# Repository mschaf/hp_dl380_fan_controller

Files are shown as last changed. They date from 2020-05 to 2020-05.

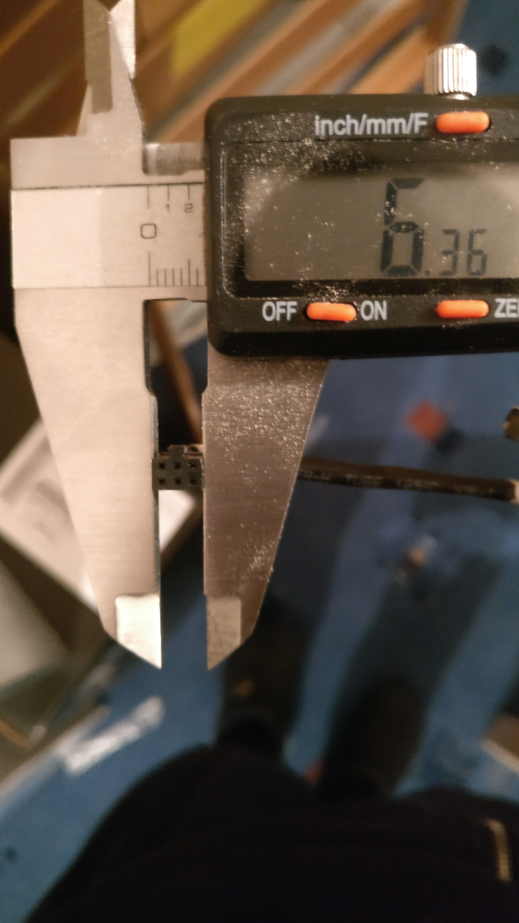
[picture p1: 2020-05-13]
reference images/IMG_20200121_184714.jpg

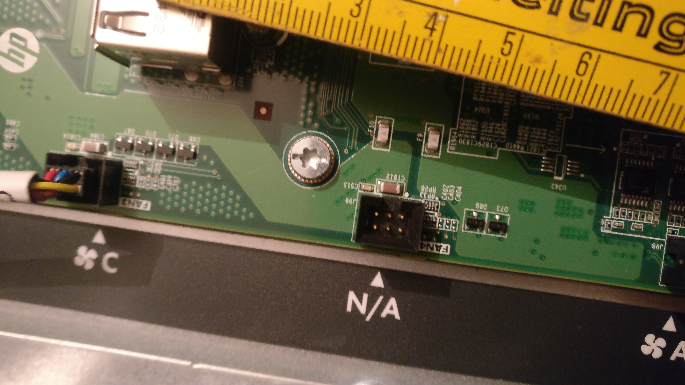
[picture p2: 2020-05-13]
reference images/IMG_20200121_184526.jpg

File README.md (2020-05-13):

## HP DL380 Fan Controller

A fan controller for my DL380e gen8, should work with similar servers as well. It takes the fan signal from the mainboard and divides it by 2, expect it is over 70% then it just passed it as it is. 

It gets its power and commands from the internal USB port of the server. It acts like a serial device and can be configured via the serial console. 

Firmware for the PIC microcontroller is written with MPLAB X in c.
The PCB layout is made in KiCAD and can be ordered from services like JLCPCB with the files from the gerbers directory.

Its not perfect, there are still some features it should have, like saving the config to survive a power cylce.

The cables needed can either be hacked together with some spare fan cables from HP or made yourself. The connectors are somewhat custom, or at least I could not find them online. You can use 2mm pitch standart pin sockets and grind them down a litte ti fit in the header on the mainbaord.

Fan Controller Installed

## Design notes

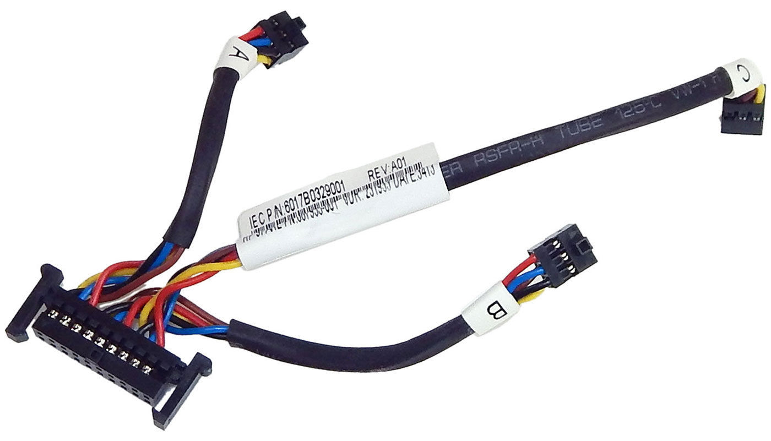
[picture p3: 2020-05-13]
reference images/s-l1600.jpg

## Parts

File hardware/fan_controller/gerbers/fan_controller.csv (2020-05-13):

Comment | Designator | Footprint
10k? | R12,R1,R2,R3,R4,R5,R6,R7,R11,R13,R14,R15,R16 | R_0805_2012Metric
10uF | C1,C17 | C_1206_3216Metric
100nF | C2,C3,C4,C5,C6,C7,C8,C9,C10,C11,C12,C13 | C_0805_2012Metric
15pF | C14,C15 | C_0805_2012Metric
10uF | C16 | CP_Elec_4x5.4
1uF | C18 | C_0805_2012Metric
LED_Dual_AACC | D1,D2,D3 | EVL 15-22 R6G6C
Conn_02x05_Odd_Even | J1,J2 | IDC-Header_2x05_P2.54mm_Vertical
ICSP | J3 | PinSocket_1x05_P2.54mm_Vertical
Jumper_NC_Dual | JP1 | PinSocket_1x03_P2.54mm_Vertical
100? | R8,R9,R10,R17,R18,R19,R20 | R_0805_2012Metric
100K? | R21 | R_0805_2012Metric
390? | R22 | R_0805_2012Metric
470? | R23,R24,R25,R26,R27,R28 | R_0805_2012Metric
240? | R29 | R_0805_2012Metric
PIC24FJ128GB204 | U1 | TQFP-44_10x10mm_P0.8mm
LD1117-R | U2 | SOT-223-3_TabPin2
8 MHz | Y1 | smd_quarz

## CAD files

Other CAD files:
hardware/fan_controller/gerbers/fan_controller-PTH.dxf

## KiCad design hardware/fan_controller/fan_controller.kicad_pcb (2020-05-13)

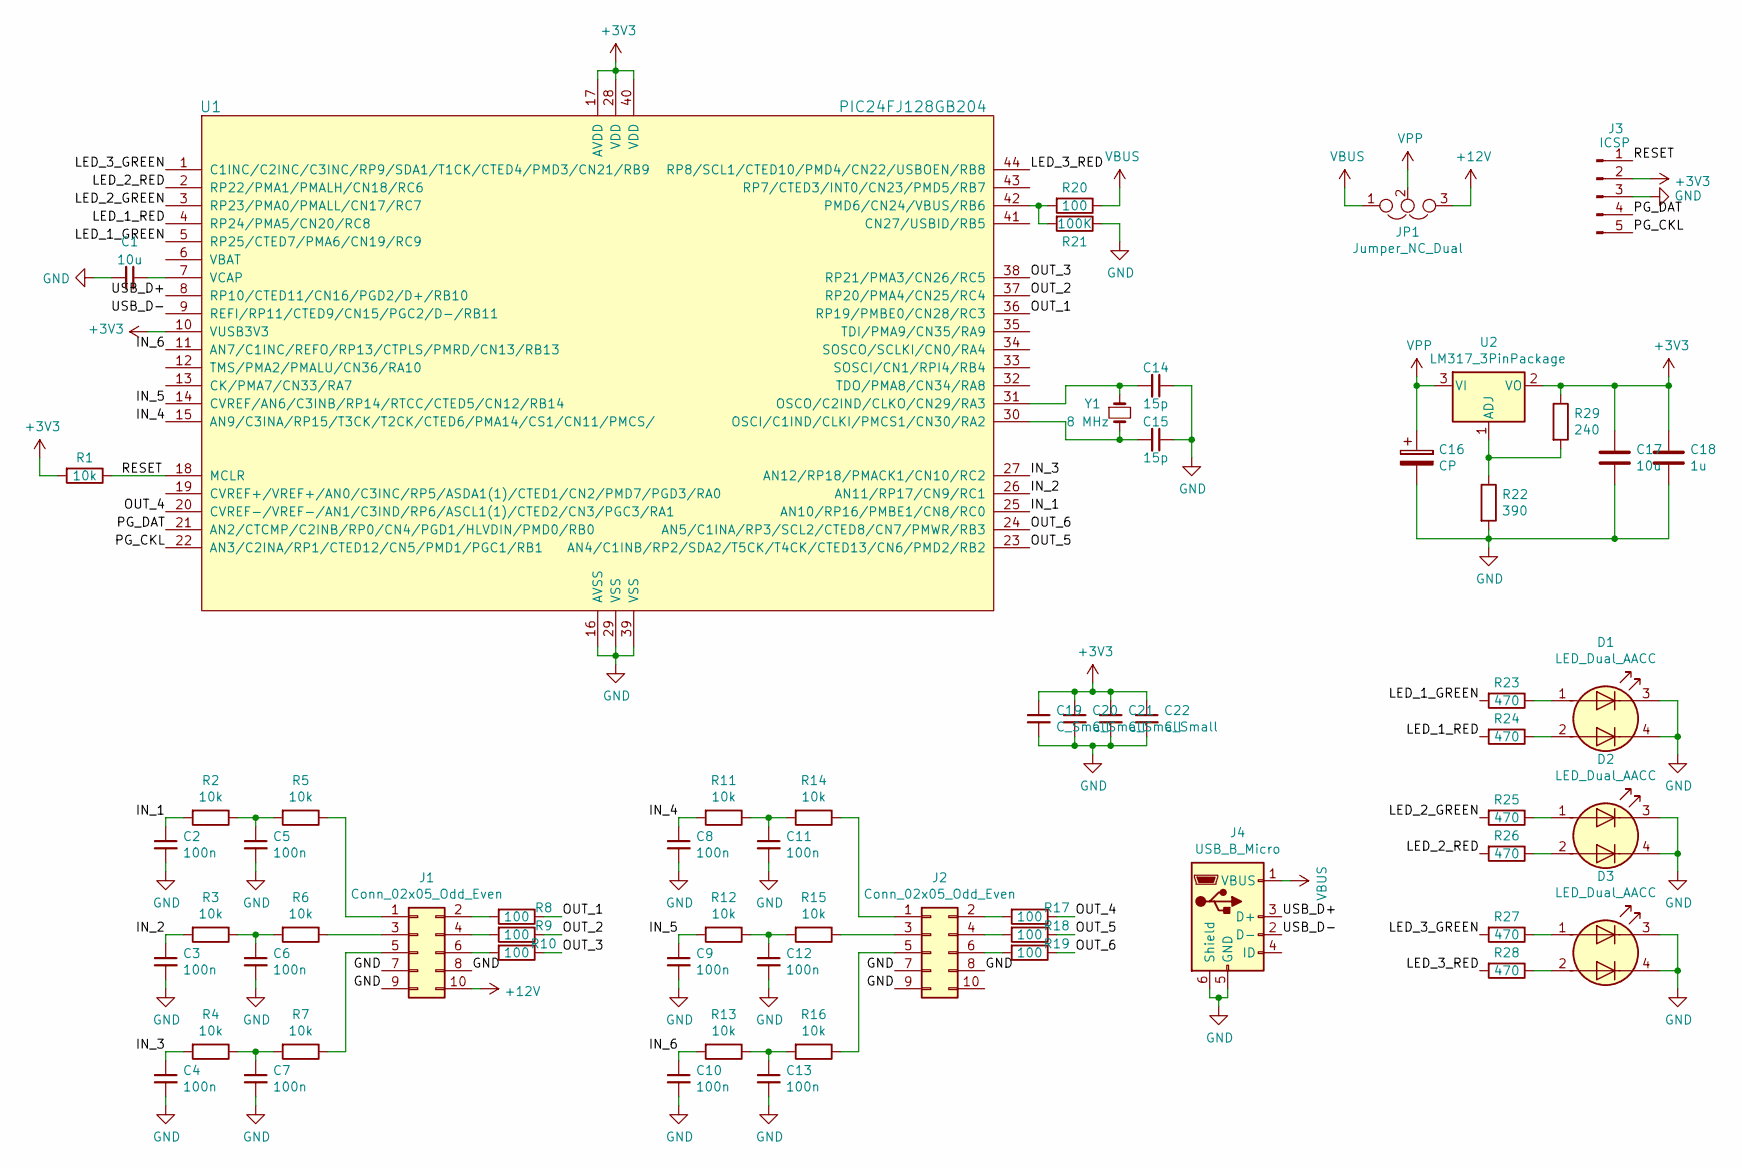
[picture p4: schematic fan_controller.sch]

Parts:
C1, C17: 10u; C_1206_3216Metric
C2, C3, C4, C5, C6, C7, C8, C9, C10, C11, C12, C13: 100n; C_0805_2012Metric
C14, C15: 15p; C_0805_2012Metric
C16: CP; CP_Elec_4x5.4
C18: 1u; C_0805_2012Metric
C19, C20, C21, C22: C_Small; C_0805_2012Metric
D1, D2, D3: LED_Dual_AACC; EVL 15-22 R6G6C
J1, J2: Conn_02x05_Odd_Even; IDC-Header_2x05_P2.54mm_Vertical
J3: ICSP; PinSocket_1x05_P2.54mm_Vertical
J4: USB_B_Micro; USB_BWM
JP1: Jumper_NC_Dual; PinSocket_1x03_P2.54mm_Vertical
R1, R2, R3, R4, R5, R6, R7, R11, R12, R13, R14, R15, R16: 10k; R_0805_2012Metric
R8, R9, R10, R17, R18, R19, R20: 100; R_0805_2012Metric
R21: 100K; R_0805_2012Metric
R22: 390; R_0805_2012Metric
R23, R24, R25, R26, R27, R28: 470; R_0805_2012Metric
R29: 240; R_0805_2012Metric
U1: PIC24FJ128GB204; TQFP-44_10x10mm_P0.8mm
U2: LM317_3PinPackage; SOT-223-3_TabPin2
Y1: 8 MHz; smd_quarz

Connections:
+3V3: C17.1, C18.1, C19.1, C20.1, C21.1, C22.1, J3.2, R1.2, R29.1, U1.10 (VUSB3V3), U1.17 (AVDD), U1.28 (VDD), U1.40 (VDD), U2.2 (VO)
+12V: J1.10, JP1.3
/IN_1: C2.1, R2.2, U1.25 (AN10/RP16/PMBE1/CN8/RC0)
/IN_2: C3.1, R3.2, U1.26 (AN11/RP17/CN9/RC1)
/IN_3: C4.1, R4.2, U1.27 (AN12/RP18/PMACK1/CN10/RC2)
/IN_4: C8.1, R11.2, U1.15 (AN9/C3INA/RP15/T3CK/T2CK/CTED6/PMA14/CS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)
/IN_5: C9.1, R12.2, U1.14 (CVREF/AN6/C3INB/RP14/RTCC/CTED5/CN12/RB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)
/IN_6: C10.1, R13.2, U1.11 (AN7/C1INC/REFO/RP13/CTPLS/PMRD/CN13/RB13)
/LED_1_GREEN: R23.2, U1.5 (RP25/CTED7/PMA6/CN19/RC9)
/LED_1_RED: R24.2, U1.4 (RP24/PMA5/CN20/RC8)
/LED_2_GREEN: R25.2, U1.3 (RP23/PMA0/PMALL/CN17/RC7)
/LED_2_RED: R26.2, U1.2 (RP22/PMA1/PMALH/CN18/RC6)
/LED_3_GREEN: R27.2, U1.1 (C1INC/C2INC/C3INC/RP9/SDA1/T1CK/CTED4/P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)
/LED_3_RED: R28.2, U1.44 (RP8/SCL1/CTED10/PMD4/CN22/USBOEN/RB8)
/OUT_1: R8.1, U1.36 (RP19/PMBE0/CN28/RC3)
/OUT_2: R9.1, U1.37 (RP20/PMA4/CN25/RC4)
/OUT_3: R10.1, U1.38 (RP21/PMA3/CN26/RC5)
/OUT_4: R17.1, U1.20 (CVREF-/VREF-/AN1/C3IND/RP6/ASCL1(1)/CTE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)
/OUT_5: R18.1, U1.23 (AN4/C1INB/RP2/SDA2/T5CK/T4CK/CTED13/CN6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)
/OUT_6: R19.1, U1.24 (AN5/C1INA/RP3/SCL2/CTED8/CN7/PMWR/RB3)
/PG_CKL: J3.5, U1.22 (AN3/C2INA/RP1/CTED12/CN5/PMD1/PGC1/RB1)
/PG_DAT: J3.4, U1.21 (AN2/CTCMP/C2INB/RP0/CN4/PGD1/HLVDIN/PMD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)
/RESET: J3.1, R1.1, U1.18 (MCLR)
/USB_D+: J4.3 (D+), U1.8 (RP10/CTED11/CN16/PGD2/D+/RB10)
/USB_D-: J4.2 (D-), U1.9 (REFI/RP11/CTED9/CN15/PGC2/D-/RB11)
GND: C1.2, C2.2, C3.2, C4.2, C5.2, C6.2, C7.2, C8.2, C9.2, C10.2, C11.2, C12.2, C13.2, C14.1, C15.1, C16.2, C17.2, C18.2, C19.2, C20.2, C21.2, C22.2, D1.3 (K1), D1.4 (K2), D2.3 (K1), D2.4 (K2), D3.3 (K1), D3.4 (K2), J1.7, J1.8, J1.9, J2.7, J2.8, J2.9, J3.3, J4.5 (GND), J4.6 (Shield), R21.1, R22.2, U1.16 (AVSS), U1.29 (VSS), U1.39 (VSS)
unnamed: C1.1, U1.7 (VCAP)
unnamed: C5.1, R2.1, R5.2
unnamed: C6.1, R3.1, R6.2
unnamed: C7.1, R4.1, R7.2
unnamed: C11.1, R11.1, R14.2
unnamed: C12.1, R12.1, R15.2
unnamed: C13.1, R13.1, R16.2
unnamed: C14.2, U1.31 (OSCO/C2IND/CLKO/CN29/RA3), Y1.1
unnamed: C15.2, U1.30 (OSCI/C1IND/CLKI/PMCS1/CN30/RA2), Y1.2
unnamed: D1.1 (A1), R23.1
unnamed: D1.2 (A2), R24.1
unnamed: D2.1 (A1), R25.1
unnamed: D2.2 (A2), R26.1
unnamed: D3.1 (A1), R27.1
unnamed: D3.2 (A2), R28.1
unnamed: J1.1, R5.1
unnamed: J1.2, R8.2
unnamed: J1.3, R6.1
unnamed: J1.4, R9.2
unnamed: J1.5, R7.1
unnamed: J1.6, R10.2
unnamed: J2.1, R14.1
unnamed: J2.2, R17.2
unnamed: J2.3, R15.1
unnamed: J2.4, R18.2
unnamed: J2.5, R16.1
unnamed: J2.6, R19.2
unnamed: R20.2, R21.2, U1.42 (PMD6/CN24/VBUS/RB6)
unnamed: R22.1, R29.2, U2.1 (ADJ)
VBUS: J4.1 (VBUS), JP1.1, R20.1
VPP: C16.1, JP1.2, U2.3 (VI)

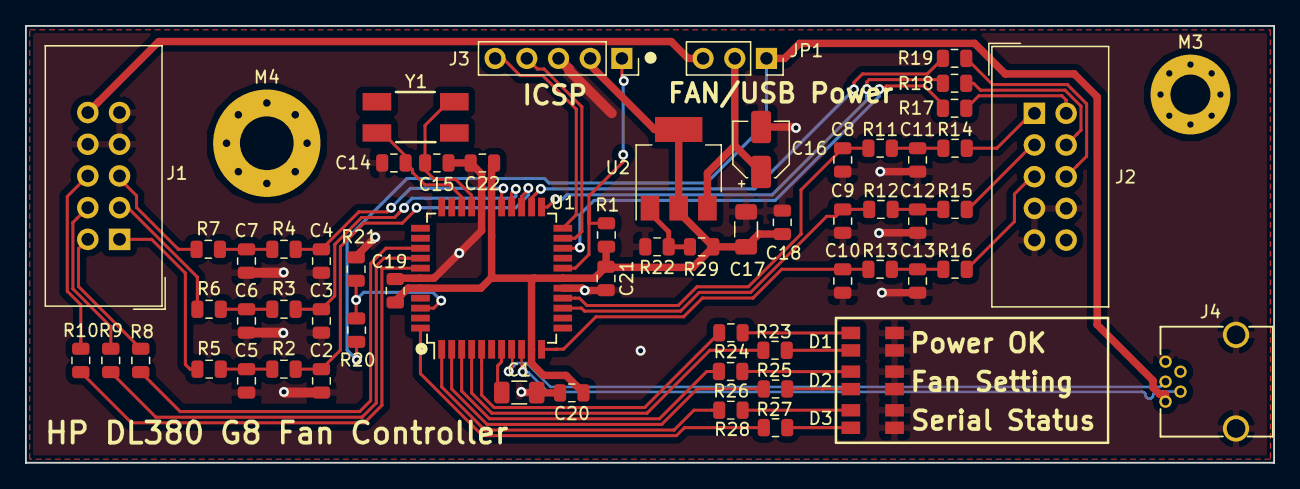
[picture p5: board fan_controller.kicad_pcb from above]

Board: 2 copper layers, 100.0 x 35.0 mm, 64 parts (0 on the bottom side), 57 nets.

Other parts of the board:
M3: MountingHole_3.2mm_M3_Pad_Via
M4: MountingHole_4.3mm_M4_Pad_Via

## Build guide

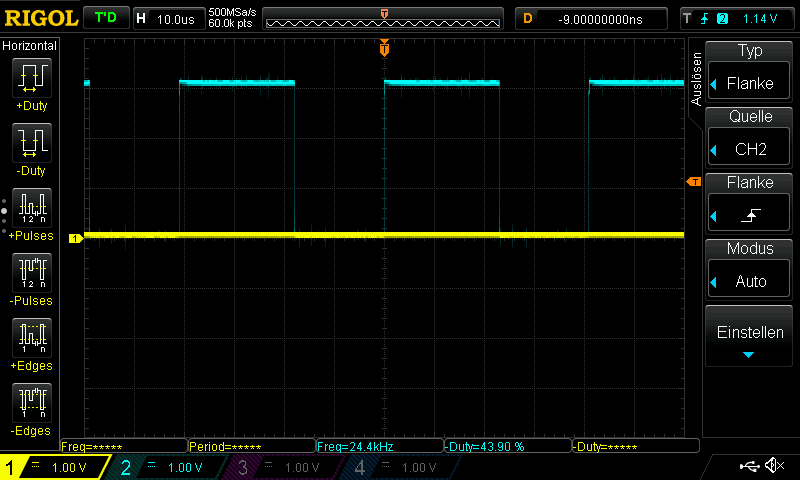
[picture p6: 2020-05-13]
reference images/DS1Z_QuickPrint3.png

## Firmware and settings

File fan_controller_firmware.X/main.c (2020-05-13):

/**
  Generated main.c file from MPLAB Code Configurator

  @Company
    Microchip Technology Inc.

  @File Name
    main.c

  @Summary
    This is the generated main.c using PIC24 / dsPIC33 / PIC32MM MCUs.

  @Description
    This source file provides main entry point for system intialization and application code development.
    Generation Information :
        Product Revision  :  PIC24 / dsPIC33 / PIC32MM MCUs - 1.95-b-SNAPSHOT
        Device            :  PIC24FJ128GB204
    The generated drivers are tested against the following:
        Compiler          :  XC16 v1.36
        MPLAB 	          :  MPLAB X v5.10
*/

/*
    (c) 2016 Microchip Technology Inc. and its subsidiaries. You may use this
    software and any derivatives exclusively with Microchip products.

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
    IN NO EVENT WILL MICROCHIP BE LIABLE FOR ANY INDIRECT, SPECIAL, PUNITIVE,
    INCIDENTAL OR CONSEQUENTIAL LOSS, DAMAGE, COST OR EXPENSE OF ANY KIND
    WHATSOEVER RELATED TO THE SOFTWARE, HOWEVER CAUSED, EVEN IF MICROCHIP HAS
    BEEN ADVISED OF THE POSSIBILITY OR THE DAMAGES ARE FORESEEABLE. TO THE
    FULLEST EXTENT ALLOWED BY LAW, MICROCHIP'S TOTAL LIABILITY ON ALL CLAIMS IN
    ANY WAY RELATED TO THIS SOFTWARE WILL NOT EXCEED THE AMOUNT OF FEES, IF ANY,
    THAT YOU HAVE PAID DIRECTLY TO MICROCHIP FOR THIS SOFTWARE.

    MICROCHIP PROVIDES THIS SOFTWARE CONDITIONALLY UPON YOUR ACCEPTANCE OF THESE
    TERMS.
*/

/**
  Section: Included Files
*/
#include "mcc_generated_files/system.h"
#include "mcc_generated_files/mcc.h"
#define    FCY    32000000UL  
#include <libpic30.h> 
#include "stdio.h"
#include "string.h"
#include <stdarg.h>

/*
                         Main application
 */

void TMR1_Interrupt(void)
{
    LED_Toggle();
}

/* 
 * Inputs:
 *     | PIN | Analog PIN
 * IN1 | C0  | AN10
 * IN2 | C1  | AN11
 * IN3 | C2  | AN12
 * IN4 | B15 | AN9
 * IN5 | B14 | AN6
 * IN6 | B13 | AN7
 * 
 * Outputs:
 *      | PIN
 * OUT1 | C3  
 * OUT2 | C4
 * OUT3 | C5
 * OUT4 | A1
 * OUT5 | B2
 * OUT6 | B3
 * 
 * Leds:
 *        | Green Pin | Red Pin
 * Power  | C9        | C8
 * Fan    | C7        | C6
 * Serial | B9        | B8
 *  
 */

void set_output(int output, int value);
int read_input(int input);
void serial_printf(const char *, ...);
void serial_console_task();
void auto_output_task();
void read_inputs();
void write_config();
void power_led_task();

uint8_t read_byte;
uint8_t bytes_in_command_buffer = 0;
static char command_buffer[64];
static char write_buffer[128];

int minimal_set_value = 10;
float reduction_factor = 0.5;
int cutoff_value = 65;

int input_values[6];
int output_values[6];

int new_tx_ready = 1;

int auto_mode = 1;
int i;

int led_cycle_count = 0;

int main(void)
{
    // Setup MCC
    SYSTEM_Initialize(); 
    TMR1_Start();

    // Setup ADC
    
    AD1CON1 = 0;
    AD1CON2 = 0;
    AD1CSSL = 0;
    AD1CON3 = 0x0002;

    AD1CON1bits.ADON = 1; // turn ADC ON
    
    // Setup ananlog inputs
    
    TRISCbits.TRISC0 = 1; // IN1
    ANSCbits.ANSC0 = 1;    
    TRISCbits.TRISC1 = 1; // IN2
    ANSCbits.ANSC1 = 1;    
    TRISCbits.TRISC2 = 1; // IN3
    ANSCbits.ANSC2 = 1;    
    TRISBbits.TRISB15 = 1; // IN4
    ANSBbits.ANSB15 = 1;
    TRISBbits.TRISB14 = 1; // IN5
    ANSBbits.ANSB14 = 1;
    TRISBbits.TRISB13 = 1; // IN6
    ANSBbits.ANSB13 = 1;
    
    while (1) // repeat continuously
    {
        read_inputs();
        auto_output_task();
        serial_console_task();
        led_task();
        
        ClrWdt();
    }
    return 1;
}

void led_task(){
    led_cycle_count ++;
    if(led_cycle_count > 30){
        led_cycle_count = 0;
         led_power_green_Toggle();
    }
    if(auto_mode){
        led_fan_green_SetHigh();
        led_fan_red_SetLow();
    }else{
        led_fan_green_SetLow();
        led_fan_red_SetHigh();
    }
}

void read_inputs(){
    for(i=0;i<6;i++){
        input_values[i] = read_input(i);
    }
}

void auto_output_task(){
    if(auto_mode){
        for(i=0;i<6;i++){
            if(input_values[i] < cutoff_value){
                output_values[i] = (int)(((float) input_values[i]) * reduction_factor);
                if(output_values[i] < minimal_set_value){
                    output_values[i] = minimal_set_value;
                }
            }else{
                output_values[i] = input_values[i];
            }
            set_output(i, output_values[i]);
        }
    }
}

void serial_console_task() {
    led_serial_green_SetLow();
    led_serial_red_SetLow();
    if( USBGetDeviceState() < CONFIGURED_STATE ){
        new_tx_ready = 1;
        return;
    }
        
    if(USBIsDeviceSuspended()){
        new_tx_ready = 1;
        return;
    }
    
    led_serial_red_SetHigh();

    if( USBUSARTIsTxTrfReady()){
        led_serial_red_SetLow();
        led_serial_green_SetHigh();
        
        
        // read byte wise
        int read_bytes = getsUSBUSART(&read_byte, 1);

        if(read_bytes > 0){
            if(read_byte == '\r'){
                
                if(new_tx_ready){
                    new_tx_ready = 0;
                    serial_printf("\r\nHP DL380e G8 Fan Controller\n\r");
                    serial_printf("Commands: get, set, auto, config get, config set\n\n\r> ");
                }

                command_buffer[bytes_in_command_buffer] = 0;
                // serial_printf("\n\rcommand: %s \n\r",command_buffer);
                
                if(bytes_in_command_buffer == 0){
                    serial_printf("\r\n");
                }else if(strcmp(command_buffer, "get") == 0){
                    serial_printf("\r\nauto mode: %d\r\nchannel | reading | output\n\r---------+---------+-------\n\r", auto_mode);
                    for(i=0;i<6;i++){
                        serial_printf("    %d    |  %3d%%   |  %3d%%   \r\n", i+1, input_values[i], output_values[i]);
                    }
                }else if(strcmp(command_buffer, "auto") == 0){
                    auto_mode = 1;
                    serial_printf("\r\nset to auto mode\n\r");
                }else if(strncmp(command_buffer, "set", 3) == 0){

                    int new_value;
                    sscanf(command_buffer, "set %d", &new_value);     

                    for(i=0;i<6;i++){
                        output_values[i] = new_value;
                        set_output(i, output_values[i]);
                    }

                    auto_mode = 0;
                    serial_printf("\r\nset all outputs to: %d%%\n\r", new_value);
                }else if(strncmp(command_buffer, "config get", 10) == 0){ 
                    serial_printf( "\r\ncurrent config:\r\n");
                    serial_printf( "  minimal set value: %d%%\n\r", minimal_set_value);        
                    serial_printf( "  reduction factor : %f\n\r", reduction_factor);    
                    serial_printf( "  cutoff value     : %d%%\n\r", cutoff_value);    
                    
                }else if(strncmp(command_buffer, "config set minimal set value", 28) == 0){ 
                    sscanf(command_buffer, "config set minimal set value %d", &minimal_set_value);
                    write_config();
                    serial_printf( "\n\rminimal set value set to: %d%%\n\r", minimal_set_value);  
                    
                }else if(strncmp(command_buffer, "config set reduction factor", 27) == 0){ 
                    sscanf(command_buffer, "config set reduction factor %f", &reduction_factor);
                    write_config();
                    serial_printf( "\n\rreduction factor set to: %f\n\r", reduction_factor);   
                    
                }else if(strncmp(command_buffer, "config set cutoff value", 10) == 0){ 
                    sscanf(command_buffer, "config set cutoff value %d", &cutoff_value);
                    write_config();
                    serial_printf( "\n\rcutoff value set to: %d%%\n\r", cutoff_value);    
                    
                }else if(strncmp(command_buffer, "take off", 8) == 0){ 
                    auto_mode = 0;
                    for(i=0;i<6;i++){
                        output_values[i] = 100;
                        set_output(i, output_values[i]);
                    }
                    serial_printf( "\n\rtaking off ...\n\r");    
                }else{
                    serial_printf("\n\runknown command\n\r");
                }
                bytes_in_command_buffer = 0;

                serial_printf("> ",command_buffer);    
            }else{
                if(read_byte == 0x7F){ //backspace
                    if(bytes_in_command_buffer > 0){
                        bytes_in_command_buffer--;
                        putUSBUSART(&read_byte, 1);
                    }
                }else{
                    if(bytes_in_command_buffer <= 64){
                        if(read_byte >= 32 && read_byte <= 126){
                            command_buffer[bytes_in_command_buffer++] = read_byte;
                            putUSBUSART(&read_byte, 1);
                        }
                    } 
                }
                
            }
        }
    }
    CDCTxService();
}

void write_config(){
    
}

void serial_printf(const char *format_string, ...){
    va_list args;
    va_start(args,format_string);
    vsprintf(write_buffer,format_string,args);
    va_end(args);
    
    putsUSBUSART(write_buffer);
    
    while(!USBUSARTIsTxTrfReady()){
        CDCTxService();
    }
}

void set_output(int output, int value){
    int set_value = (int)((float) (100 - value) * 6.4f);
    if(set_value >= 640)
        set_value = 639;
    if(set_value <= 0)
        set_value = 1;

    switch(output){
        case 0:
            OC1_PrimaryValueSet(set_value);
            break;
        case 1:
            OC2_PrimaryValueSet(set_value);
            break;
        case 2:
            OC3_PrimaryValueSet(set_value);
            break;
        case 3:
            OC4_PrimaryValueSet(set_value);
            break;
        case 4:
            OC5_PrimaryValueSet(set_value);
            break;
        case 5:
            OC6_PrimaryValueSet(set_value);
            break;
            
    }
}

int read_input(int input) {
   switch(input){
        case 0:
            AD1CHS = 10;
            break;
        case 1:
            AD1CHS = 11;
            break;
        case 2:
            AD1CHS = 12;
            break;
        case 3:
            AD1CHS = 9;
            break;
        case 4:
            AD1CHS = 6;
            break;
        case 5:
            AD1CHS = 7;
            break;
            
    }     
   
    AD1CON1bits.SAMP = 1; // start sampling...
    __delay_us(100); // Ensure the correct sampling time has elapsed
    // before starting conversion.
    AD1CON1bits.SAMP = 0; // start converting
    while (!AD1CON1bits.DONE){}; // conversion done?
    int conversion = ADC1BUF0; // yes then get ADC value
    conversion = 100 - ((int)(((float)conversion / 1024.0f) * 100));
    
    return conversion;
}

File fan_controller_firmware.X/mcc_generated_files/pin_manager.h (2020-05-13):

/**
  PIN MANAGER Generated Driver File

  @Company:
    Microchip Technology Inc.

  @File Name:
    pin_manager.h

  @Summary:
    This is the generated manager file for the PIC24 / dsPIC33 / PIC32MM MCUs device.  This manager
    configures the pins direction, initial state, analog setting.
    The peripheral pin select, PPS, configuration is also handled by this manager.

  @Description:
    This source file provides implementations for PIN MANAGER.
    Generation Information :
        Product Revision  :  PIC24 / dsPIC33 / PIC32MM MCUs - 1.95-b-SNAPSHOT
        Device            :  PIC24FJ128GB204
    The generated drivers are tested against the following:
        Compiler          :  XC16 v1.36
        MPLAB 	          :  MPLAB X v5.10
*/

/*
    (c) 2016 Microchip Technology Inc. and its subsidiaries. You may use this
    software and any derivatives exclusively with Microchip products.

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
    IN NO EVENT WILL MICROCHIP BE LIABLE FOR ANY INDIRECT, SPECIAL, PUNITIVE,
    INCIDENTAL OR CONSEQUENTIAL LOSS, DAMAGE, COST OR EXPENSE OF ANY KIND
    WHATSOEVER RELATED TO THE SOFTWARE, HOWEVER CAUSED, EVEN IF MICROCHIP HAS
    BEEN ADVISED OF THE POSSIBILITY OR THE DAMAGES ARE FORESEEABLE. TO THE
    FULLEST EXTENT ALLOWED BY LAW, MICROCHIP'S TOTAL LIABILITY ON ALL CLAIMS IN
    ANY WAY RELATED TO THIS SOFTWARE WILL NOT EXCEED THE AMOUNT OF FEES, IF ANY,
    THAT YOU HAVE PAID DIRECTLY TO MICROCHIP FOR THIS SOFTWARE.

    MICROCHIP PROVIDES THIS SOFTWARE CONDITIONALLY UPON YOUR ACCEPTANCE OF THESE
    TERMS.
*/

#ifndef _PIN_MANAGER_H
#define _PIN_MANAGER_H
/**
    Section: Includes
*/
#include <xc.h>

/**
    Section: Device Pin Macros
*/
/**
  @Summary
    Sets the GPIO pin, RB13, high using LATB13.

  @Description
    Sets the GPIO pin, RB13, high using LATB13.

  @Preconditions
    The RB13 must be set to an output.

  @Returns
    None.

  @Param
    None.

  @Example
    <code>
    // Set RB13 high (1)
    LED_SetHigh();
    </code>

*/
#define LED_SetHigh()          _LATB13 = 1
/**
  @Summary
    Sets the GPIO pin, RB13, low using LATB13.

  @Description
    Sets the GPIO pin, RB13, low using LATB13.

  @Preconditions
    The RB13 must be set to an output.

  @Returns
    None.

  @Param
    None.

  @Example
    <code>
    // Set RB13 low (0)
    LED_SetLow();
    </code>

*/
#define LED_SetLow()           _LATB13 = 0
/**
  @Summary
    Toggles the GPIO pin, RB13, using LATB13.

  @Description
    Toggles the GPIO pin, RB13, using LATB13.

  @Preconditions
    The RB13 must be set to an output.

  @Returns
    None.

  @Param
    None.

  @Example
    <code>
    // Toggle RB13
    LED_Toggle();
    </code>

*/
#define LED_Toggle()           _LATB13 ^= 1
/**
  @Summary
    Reads the value of the GPIO pin, RB13.

  @Description
    Reads the value of the GPIO pin, RB13.

  @Preconditions
    None.

  @Returns
    None.

  @Param
    None.

  @Example
    <code>
    uint16_t portValue;

    // Read RB13
    postValue = LED_GetValue();
    </code>

*/
#define LED_GetValue()         _RB13
/**
  @Summary
    Configures the GPIO pin, RB13, as an input.

  @Description
    Configures the GPIO pin, RB13, as an input.

  @Preconditions
    None.

  @Returns
    None.

  @Param
    None.

  @Example
    <code>
    // Sets the RB13 as an input
    LED_SetDigitalInput();
    </code>

*/
#define LED_SetDigitalInput()  _TRISB13 = 1
/**
  @Summary
    Configures the GPIO pin, RB13, as an output.

  @Description
    Configures the GPIO pin, RB13, as an output.

  @Preconditions
    None.

  @Returns
    None.

  @Param
    None.

  @Example
    <code>
    // Sets the RB13 as an output
    LED_SetDigitalOutput();
    </code>

*/
#define LED_SetDigitalOutput() _TRISB13 = 0
/**
  @Summary
    Sets the GPIO pin, RB8, high using LATB8.

  @Description
    Sets the GPIO pin, RB8, high using LATB8.

  @Preconditions
    The RB8 must be set to an output.

  @Returns
    None.

  @Param
    None.

  @Example
    <code>
    // Set RB8 high (1)
    led_serial_red_SetHigh();
    </code>

*/
#define led_serial_red_SetHigh()          _LATB8 = 1
/**
  @Summary
    Sets the GPIO pin, RB8, low using LATB8.

  @Description
    Sets the GPIO pin, RB8, low using LATB8.

  @Preconditions
    The RB8 must be set to an output.

  @Returns
    None.

  @Param
    None.

  @Example
    <code>
    // Set RB8 low (0)
    led_serial_red_SetLow();
    </code>

*/
#define led_serial_red_SetLow()           _LATB8 = 0
/**
  @Summary
    Toggles the GPIO pin, RB8, using LATB8.

  @Description
    Toggles the GPIO pin, RB8, using LATB8.

  @Preconditions
    The RB8 must be set to an output.

  @Returns
    None.

  @Param
    None.

  @Example
    <code>
    // Toggle RB8
    led_serial_red_Toggle();
    </code>

*/
#define led_serial_red_Toggle()           _LATB8 ^= 1
/**
  @Summary
    Reads the value of the GPIO pin, RB8.

  @Description
    Reads the value of the GPIO pin, RB8.

  @Preconditions
    None.

  @Returns
    None.

  @Param
    None.

  @Example
    <code>
    uint16_t portValue;

    // Read RB8
    postValue = led_serial_red_GetValue();
    </code>

*/
#define led_serial_red_GetValue()         _RB8
/**
  @Summary
    Configures the GPIO pin, RB8, as an input.

  @Description
    Configures the GPIO pin, RB8, as an input.

  @Preconditions
    None.

  @Returns
    None.

  @Param
    None.

  @Example
    <code>
    // Sets the RB8 as an input
    led_serial_red_SetDigitalInput();
    </code>

*/
#define led_serial_red_SetDigitalInput()  _TRISB8 = 1
/**
  @Summary
    Configures the GPIO pin, RB8, as an output.

  @Description
    Configures the GPIO pin, RB8, as an output.

  @Preconditions
    None.

  @Returns
    None.

  @Param
    None.

  @Example
    <code>
    // Sets the RB8 as an output
    led_serial_red_SetDigitalOutput();
    </code>

*/
#define led_serial_red_SetDigitalOutput() _TRISB8 = 0
/**
  @Summary
    Sets the GPIO pin, RB9, high using LATB9.

  @Description
    Sets the GPIO pin, RB9, high using LATB9.

  @Preconditions
    The RB9 must be set to an output.

  @Returns
    None.

  @Param
    None.

  @Example
    <code>
    // Set RB9 high (1)
    led_serial_green_SetHigh();
    </code>

*/
#define led_serial_green_SetHigh()          _LATB9 = 1
/**
  @Summary
    Sets the GPIO pin, RB9, low using LATB9.

  @Description
    Sets the GPIO pin, RB9, low using LATB9.

  @Preconditions
    The RB9 must be set to an output.

  @Returns
    None.

  @Param
    None.

  @Example
    <code>
    // Set RB9 low (0)
    led_serial_green_SetLow();
    </code>

*/
#define led_serial_green_SetLow()           _LATB9 = 0
/**
  @Summary
    Toggles the GPIO pin, RB9, using LATB9.

  @Description
    Toggles the GPIO pin, RB9, using LATB9.

  @Preconditions
    The RB9 must be set to an output.

  @Returns
    None.

  @Param
    None.

  @Example
    <code>
    // Toggle RB9
    led_serial_green_Toggle();
    </code>
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
